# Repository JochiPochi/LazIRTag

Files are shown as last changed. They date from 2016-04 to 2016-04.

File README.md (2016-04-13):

# LaZIR Tag
Arduino based LaserTag System

BOM: https://docs.google.com/a/cyphyworks.com/spreadsheets/d/1MXdYDq4qyfqy3L1gnKtGEeZ4zqiRnnMYT2sN9ClZJ-U/edit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

REFERENCE:

IR Receiver Info - http://uk.farnell.com/vishay/tsop4838/ir-receiver-38khz/dp/4913190

IR Receiver Datasheet - http://www.farnell.com/datasheets/1693301.pdf

IR Reference - https://learn.adafruit.com/downloads/pdf/ir-sensor.pdf

Wifi Reference - https://espressif.com/en/products/esp8266/

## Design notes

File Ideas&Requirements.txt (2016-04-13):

Arena
  Two team bases
    Health Station
    Mounted Gun to protect base
      Kasey's Desk
      Skynet
  Cool Ambiance B)
  
Apparel
  Vest with Sensors
  
Weapons
  Weapon Types
    Semi-automatic Rifle - More points, less damage
      Trigger
    Shotgun - More damage, less points
      Trigger and Pump
  Speaker
    Shooting Sound Affect
    Universal Alerts
  Health Indication
    Can heal back at base
    Lose points for dying - have to "respawn" at health station
  Light indicator when shooting

Future Expansions
  CTF - electronic flag system
  Weaponized Grenade

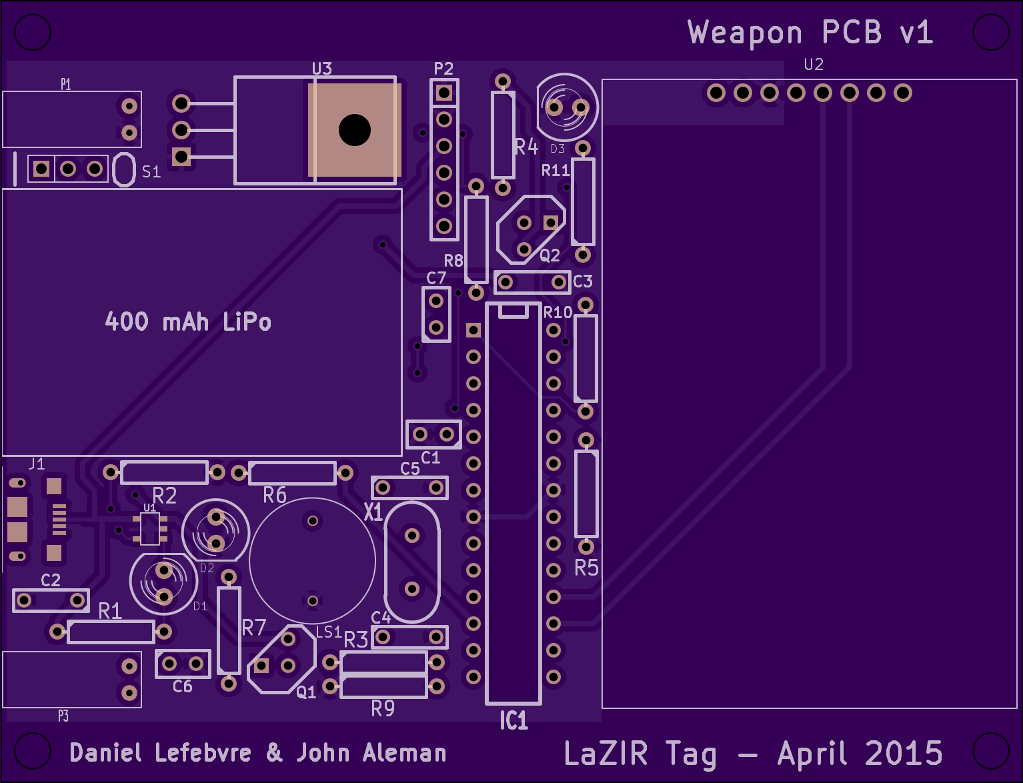
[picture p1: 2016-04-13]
KiCad/Rev1/Weapon/weap.png

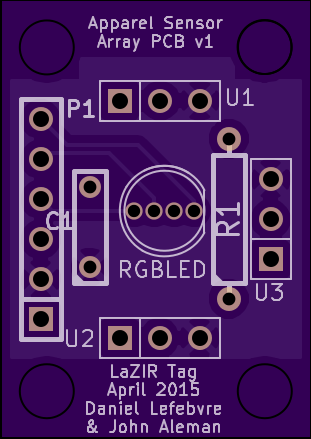
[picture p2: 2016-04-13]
KiCad/Rev1/IR-Reciever/irsens.png

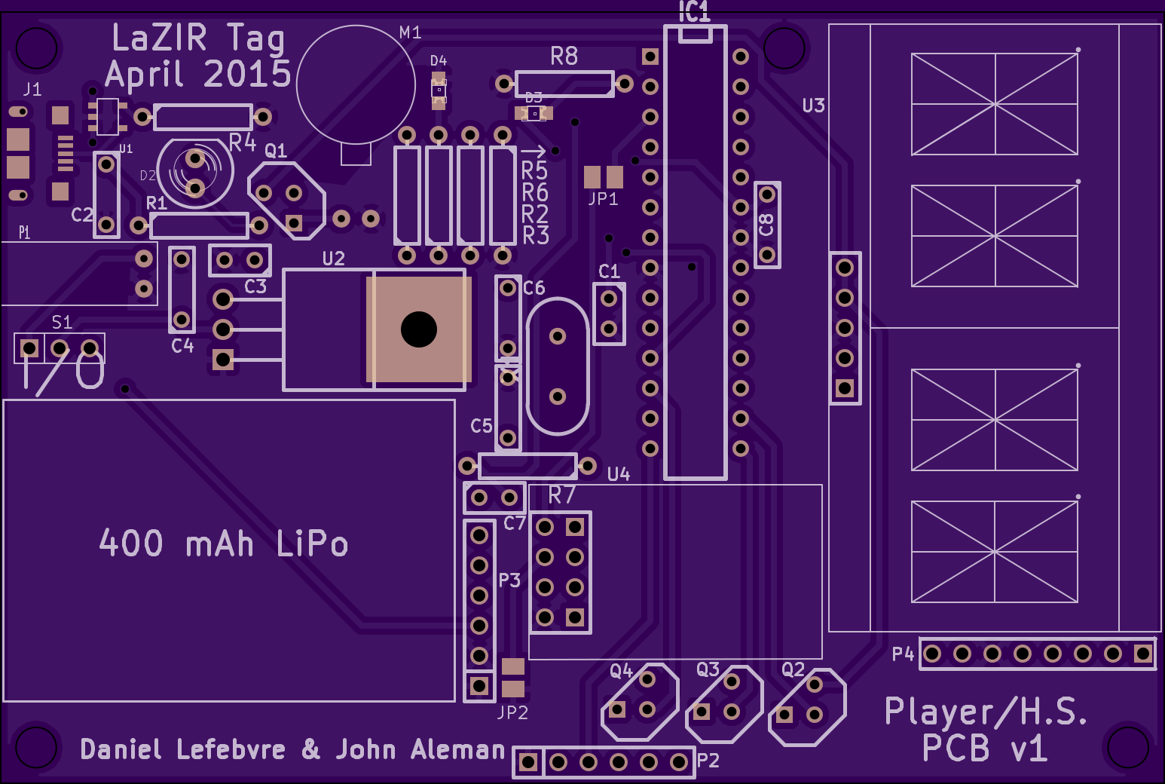
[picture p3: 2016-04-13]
KiCad/Rev1/Player-Health/plyrhs.png

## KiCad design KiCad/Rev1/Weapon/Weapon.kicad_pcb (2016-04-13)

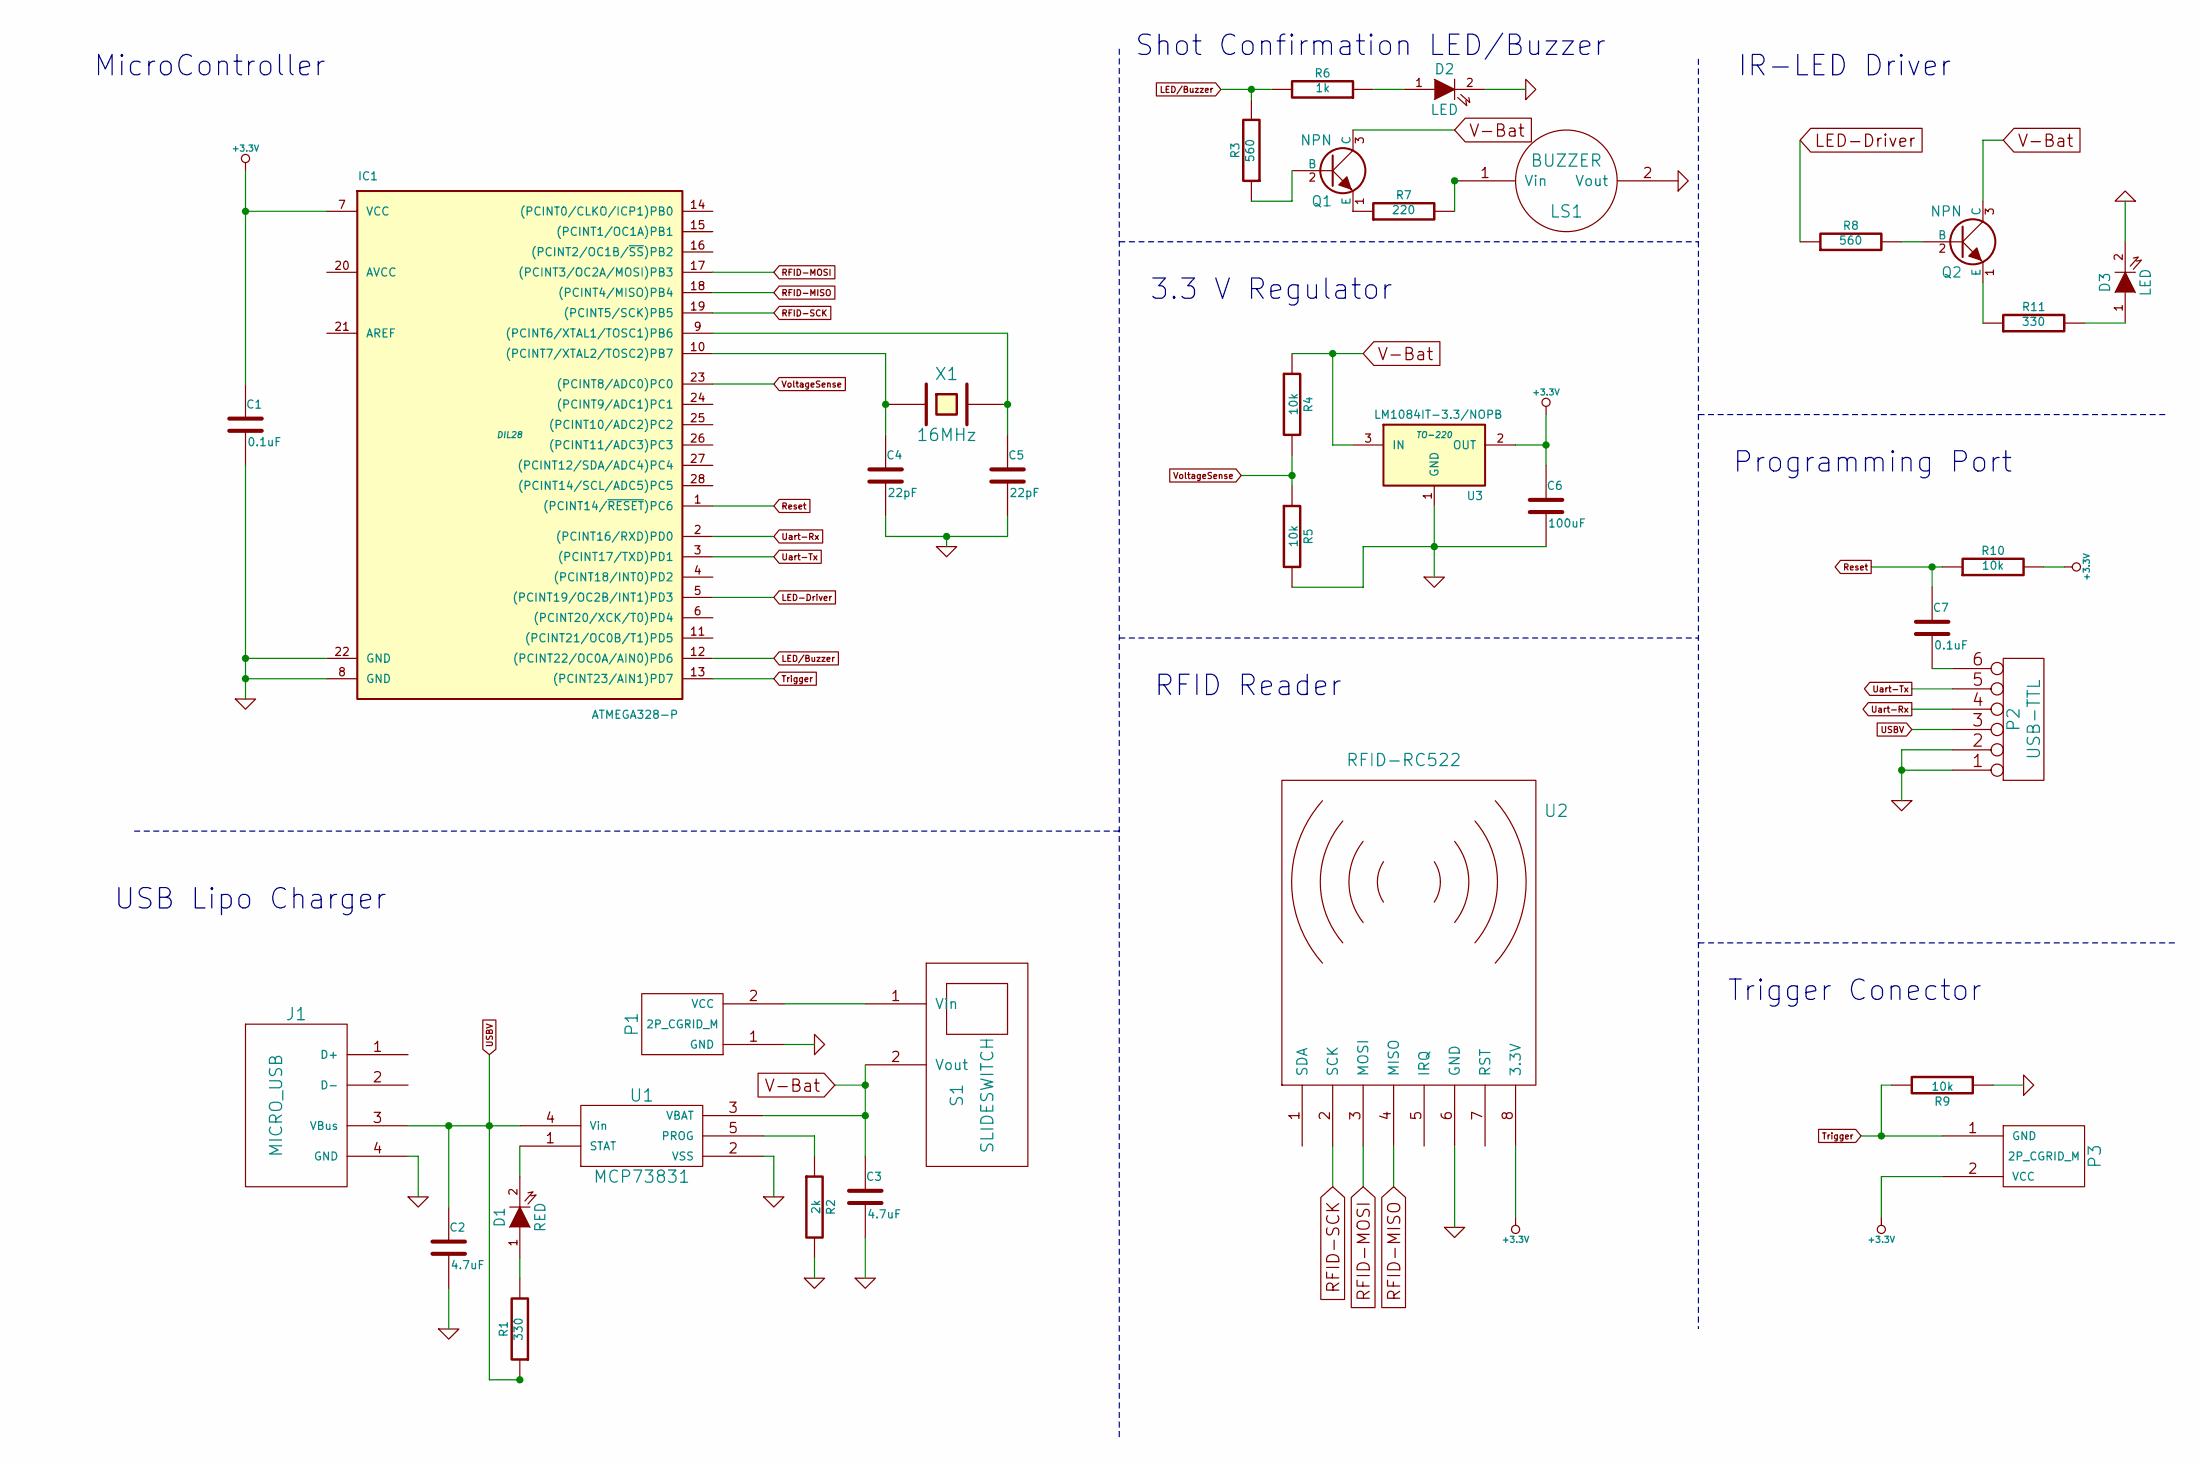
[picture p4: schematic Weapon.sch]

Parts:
C1, C7: 0.1uF
C2, C3: 4.7uF
C4, C5: 22pF
C6: 100uF
D1: RED
D2, D3: LED
IC1: ATMEGA328-P; DIL28
J1: MICRO_USB
LS1: BUZZER
P1: 2P_CGRID_M
P2: USB-TTL
P3: 2P_CGRID_M
Q1, Q2: NPN
R1, R11: 330
R2: 2k
R3, R8: 560
R4, R5, R9, R10: 10k
R6: 1k
R7: 220
S1: SLIDESWITCH
U1: MCP73831
U2: RFID-RC522
U3: LM1084IT-3.3/NOPB; TO-220
X1: 16MHz

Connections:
+3.3V: C1.1, C6.1, IC1.7 (VCC), P3.2 (VCC), R10.2, U2.8 (3.3V), U3.2 (OUT)
GND: C1.2, C2.2, C3.2, C4.2, C5.2, C6.2, D2.2 (K), D3.2 (K), IC1.8 (GND), IC1.22 (GND), J1.4 (GND), LS1.2 (Vout), P1.1 (GND), P2.1, P2.2, R2.2, R5.2, R9.1, U1.2 (VSS), U2.6 (GND), U3.1 (GND)
LED-Driver: IC1.5 ((PCINT19/OC2B/INT1)PD3), R8.1
LED/Buzzer: IC1.12 ((PCINT22/OC0A/AIN0)PD6), R3.2, R6.2
unnamed: P1.2 (VCC), S1.1 (Vin)
unnamed: D1.2 (K), U1.1 (STAT)
unnamed: D1.1 (A), R1.2
unnamed: R2.1, U1.5 (PROG)
unnamed: Q1.2 (B), R3.1
unnamed: Q1.1 (E), R7.1
unnamed: LS1.1 (Vin), R7.2
unnamed: D2.1 (A), R6.1
unnamed: C5.1, IC1.9 ((PCINT6/XTAL1/TOSC1)PB6), X1.2
unnamed: C4.1, IC1.10 ((PCINT7/XTAL2/TOSC2)PB7), X1.1
unnamed: C7.2, P2.6
unnamed: Q2.2 (B), R8.2
unnamed: D3.1 (A), R11.2
unnamed: Q2.1 (E), R11.1
RFID-MISO: IC1.18 ((PCINT4/MISO)PB4), U2.4 (MISO)
RFID-MOSI: IC1.17 ((PCINT3/OC2A/MOSI)PB3), U2.3 (MOSI)
RFID-SCK: IC1.19 ((PCINT5/SCK)PB5), U2.2 (SCK)
Reset: C7.1, IC1.1 ((PCINT14/~RESET~)PC6), R10.1
Trigger: IC1.13 ((PCINT23/AIN1)PD7), P3.1 (GND), R9.2
USBV: C2.1, J1.3 (VBus), P2.3, R1.1, U1.4 (Vin)
Uart-Rx: IC1.2 ((PCINT16/RXD)PD0), P2.4
Uart-Tx: IC1.3 ((PCINT17/TXD)PD1), P2.5
V-Bat: C3.1, Q1.3 (C), Q2.3 (C), R4.1, S1.2 (Vout), U1.3 (VBAT), U3.3 (IN)
VoltageSense: IC1.23 ((PCINT8/ADC0)PC0), R4.2, R5.1

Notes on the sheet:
MicroController
Shot Confirmation LED/Buzzer
3.3 V Regulator
RFID Reader
USB Lipo Charger
IR-LED Driver
Programming Port
Trigger Conector

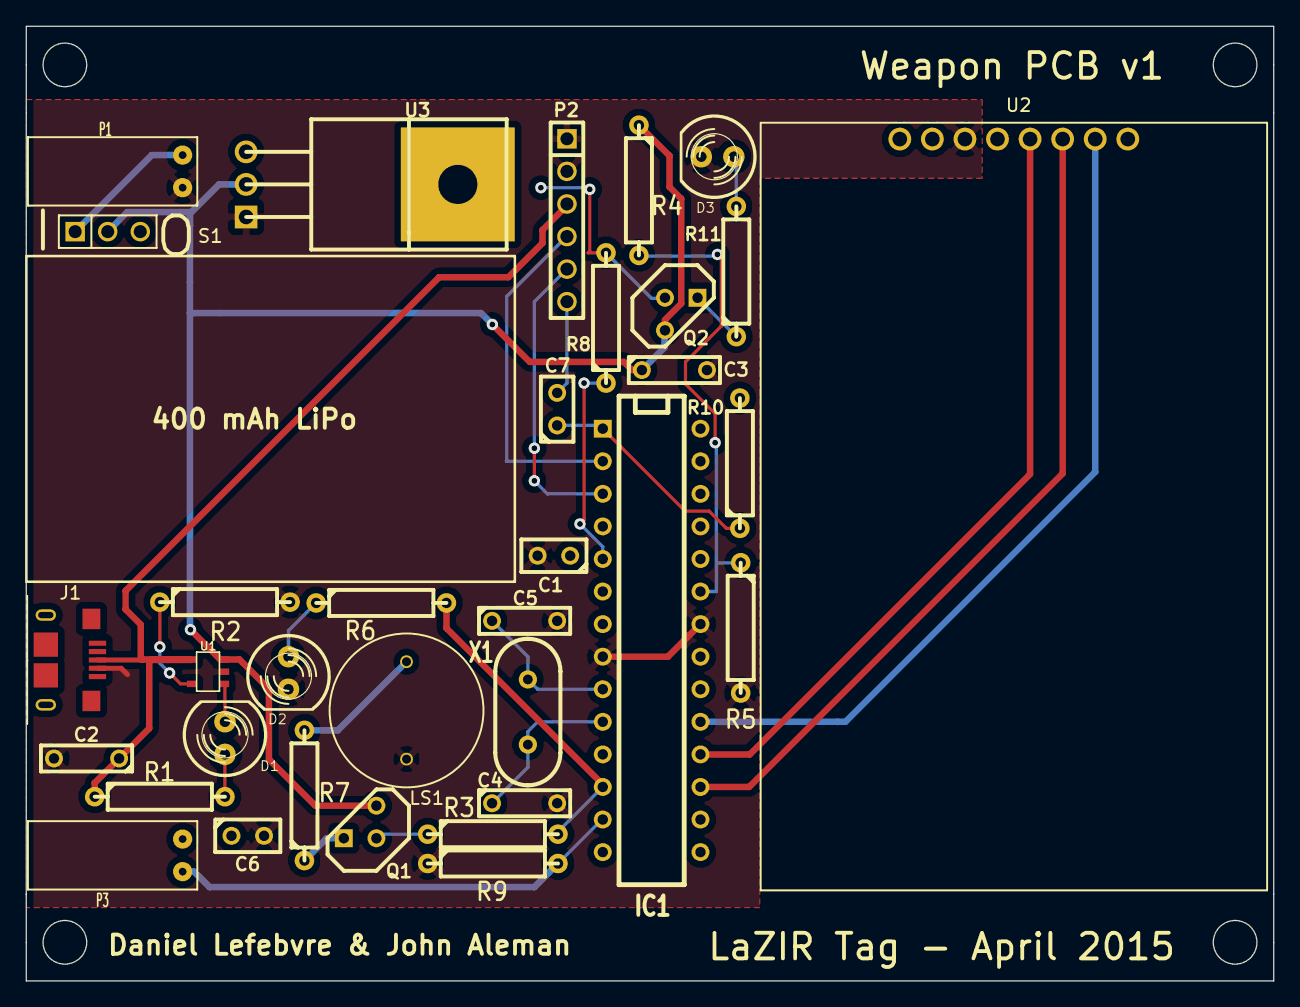
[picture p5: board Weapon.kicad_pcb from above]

Board: 2 copper layers, 97.3 x 74.4 mm, 34 parts (0 on the bottom side), 28 nets.

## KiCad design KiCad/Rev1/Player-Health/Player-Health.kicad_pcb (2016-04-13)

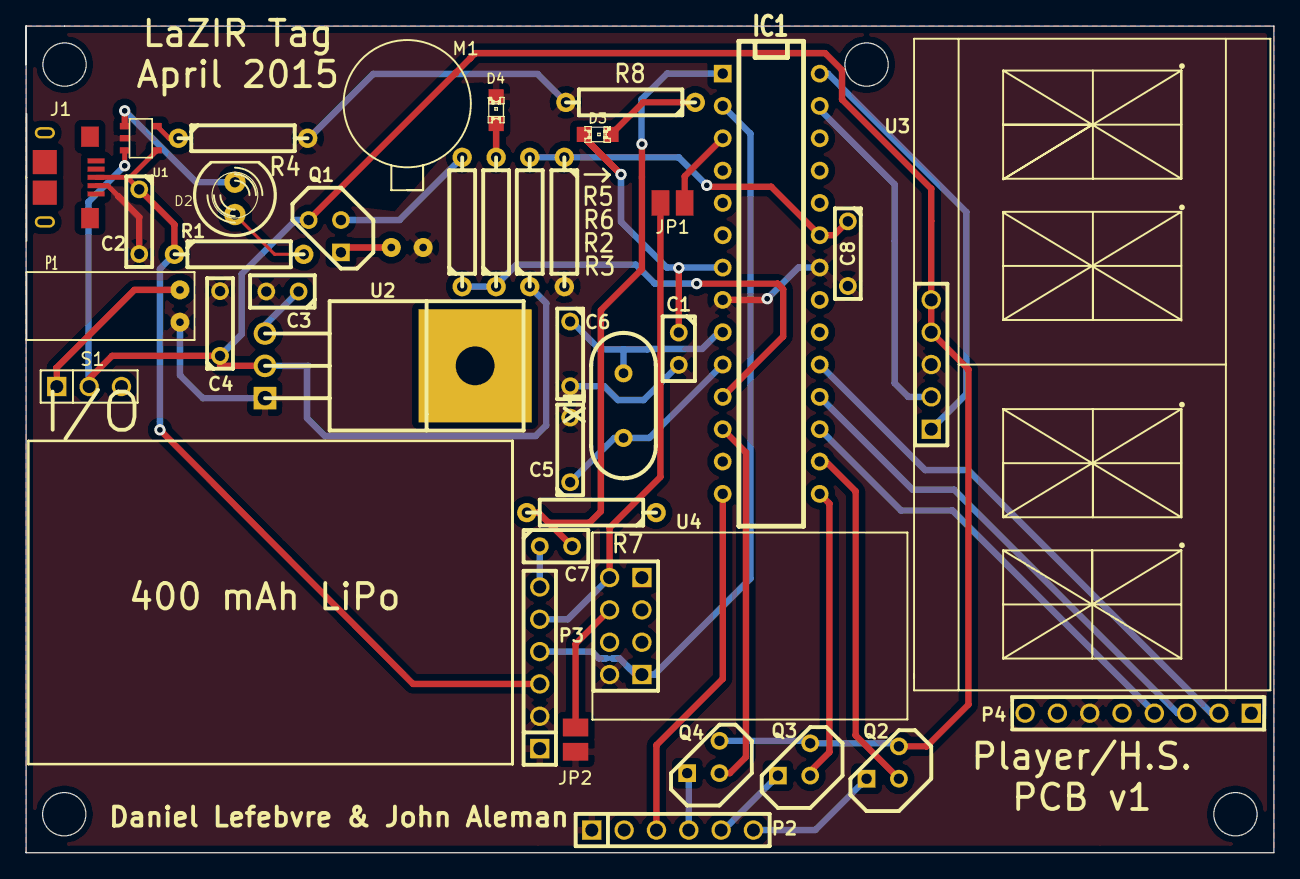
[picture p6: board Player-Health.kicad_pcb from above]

Board: 2 copper layers, 98.0 x 64.9 mm, 38 parts (0 on the bottom side), 34 nets.

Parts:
C1, C7: 0.1uF; C1
C2, C4: 4.7uF; C2
C3: 100uF; C1
C5, C6: 22pF; C2
C8: 4.7 uF; C2
D2: RED; LED-5MM
D3, D4: LED; LED-0805
IC1: ATMEGA328-P; DIP-28__300
J1: MICRO_USB; MicroUSB
JP1, JP2: JUMPER; JumperPads
M1: RUMBLE; RumbleMotor
P1: 2P_CGRID_M; 2PinMaleCGrid90Deg
P2: 6pM CGrid; PIN_ARRAY-6X1
P3: 6pM Header; PIN_ARRAY-6X1
P4: 8pF Header; pin_array_8x1
Q1, Q2, Q3, Q4: NPN; TO92
R1: 330; R4
R2, R3, R7: 10k; R4
R4: 2k; R4
R5: 560; R4
R6: 1k; R4
R8: 220; R4
S1: SLIDESWITCH; PIN_ARRAY_3X1
U1: MCP73831; SOT23-5
U2: LM1084IT-3.3/NOPB; TO220
U3: 14SLED; 14sLEDBP
U4: ESP8266; esploraWiFi
X1: CRYSTAL; HC-49V

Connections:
+3.3V: C1.1, C3.1, D3.1, IC1.7, P2.2, P4.8, R7.1, U2.2, U4.3, U4.7
GND: C1.2, C2.2, C3.2, C4.2, C5.2, C6.2, C8.2, D4.2, IC1.8, IC1.22, J1.4, JP2.2, M1.2, P1.1, P2.1, P3.1, P3.2, P4.6, R3.2, R4.2, R8.2, U1.2, U2.1, U3.3, U4.2
I2C CLK: IC1.28, U3.1
I2C DAT: IC1.27, U3.2
IR Sense: IC1.14, P2.3
LED B: IC1.15, Q3.2
LED G: IC1.12, Q4.2
LED R: IC1.16, Q2.2
MISO: IC1.18, P4.3
MOSI: IC1.17, P4.4
unnamed: P1.2, S1.1
unnamed: R4.1, U1.5
unnamed: D2.1, R1.2
unnamed: C7.1, P3.6
unnamed: M1.1, Q1.1
unnamed: JP2.1, U4.6
unnamed: D4.1, R6.2
unnamed: Q1.2, R5.2
unnamed: D3.2, R8.1
unnamed: IC1.3, JP1.1
unnamed: P2.4, Q4.1
unnamed: P2.5, Q3.1
unnamed: P2.6, Q2.1
unnamed: C5.1, IC1.10, X1.1
unnamed: C6.1, IC1.9, X1.2
unnamed: D2.2, U1.1
Reset: C7.2, IC1.1, R7.2
Rumble: IC1.11, R5.1, R6.1
SCK: IC1.19, P4.2
UART RX: IC1.2, P3.4, U4.1
UART TX: JP1.2, P3.5, U4.8
USBV: C2.1, J1.3, P3.3, R1.1, U1.4
VBatt: C4.1, Q1.3, Q2.3, Q3.3, Q4.3, R2.1, S1.2, U1.3, U2.3, U3.4, U3.5
VSense: C8.1, IC1.23, R2.2, R3.1

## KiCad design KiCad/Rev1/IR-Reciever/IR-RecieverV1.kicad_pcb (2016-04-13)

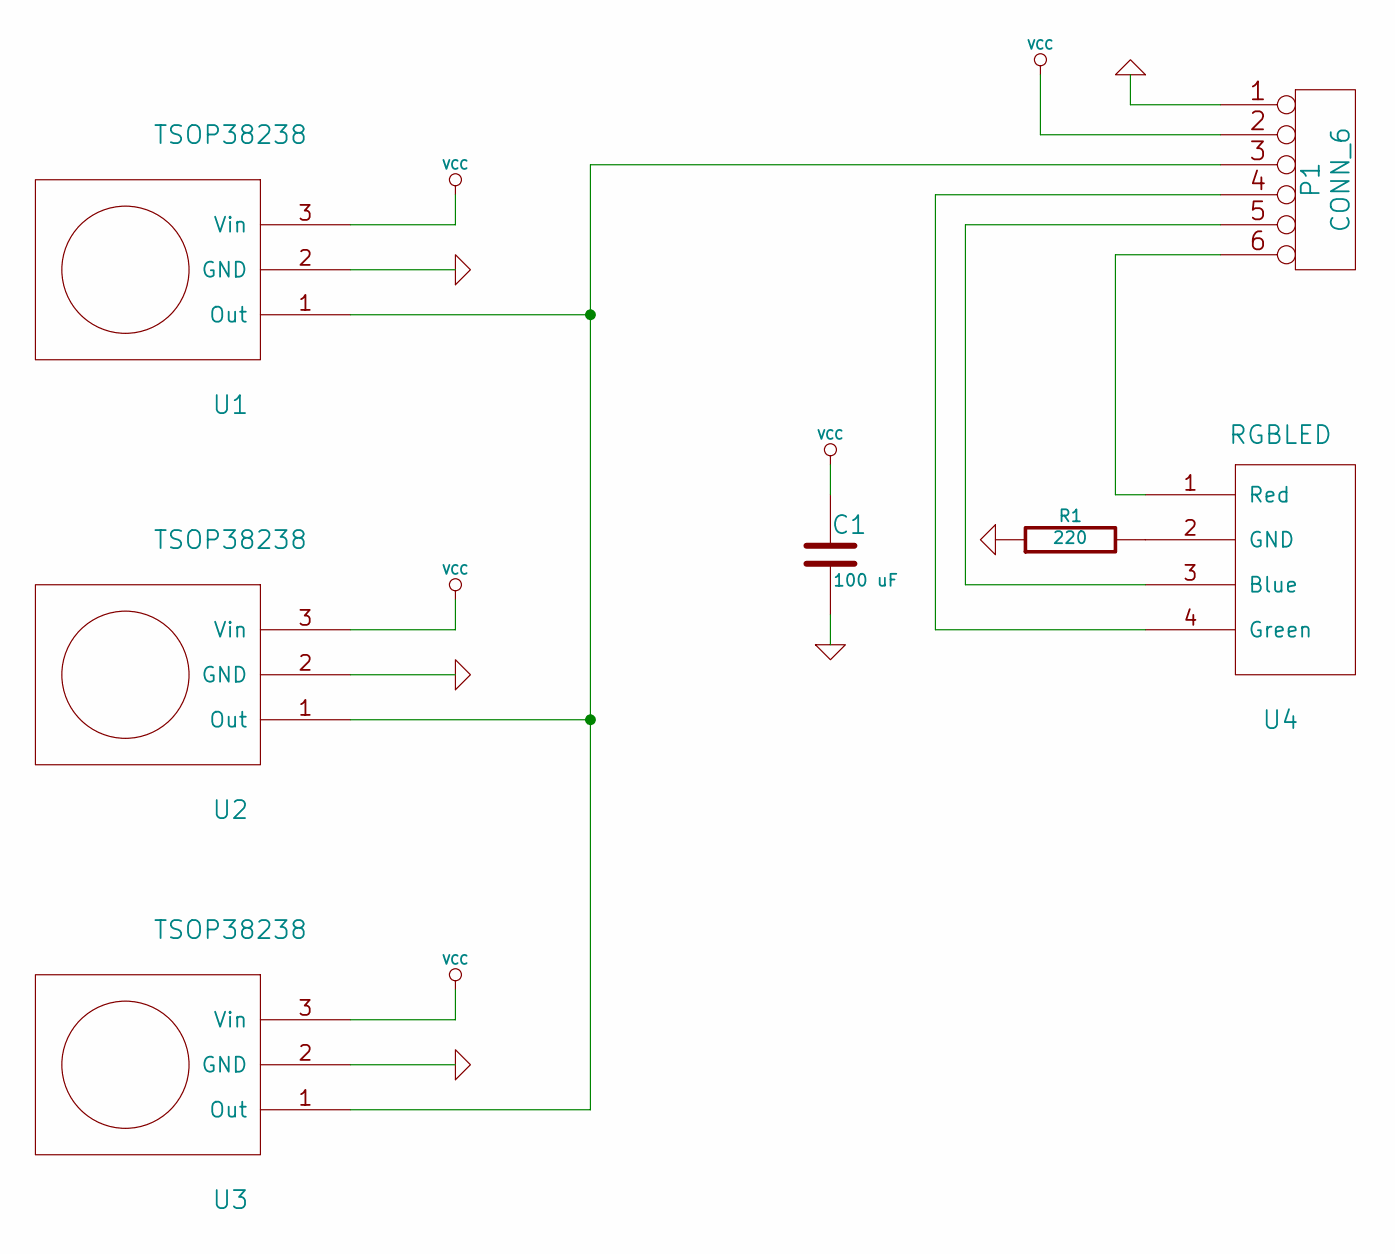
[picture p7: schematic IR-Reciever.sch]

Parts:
C1: 100 uF
P1: CONN_6
R1: 220
U1, U2, U3: TSOP38238
U4: RGBLED

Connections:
GND: C1.2, P1.1, R1.1, U1.2 (GND), U2.2 (GND), U3.2 (GND)
unnamed: P1.3, U1.1 (Out), U2.1 (Out), U3.1 (Out)
unnamed: P1.4, U4.4 (Green)
unnamed: P1.5, U4.3 (Blue)
unnamed: R1.2, U4.2 (GND)
unnamed: P1.6, U4.1 (Red)
VCC: C1.1, P1.2, U1.3 (Vin), U2.3 (Vin), U3.3 (Vin)

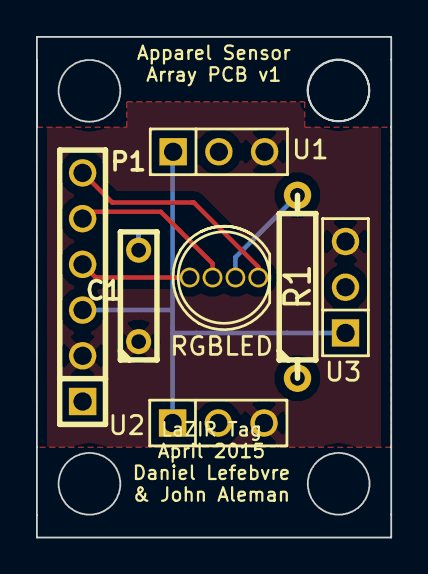
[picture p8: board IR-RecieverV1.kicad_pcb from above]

Board: 2 copper layers, 19.7 x 27.8 mm, 7 parts (0 on the bottom side), 7 nets.

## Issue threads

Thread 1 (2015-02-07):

Play/Pause with delayed repetition Sends two commands

dan52595, 2015-02-07:
Using the same delay that I read from the remote, I have an issue where the packet is received and acted upon twice if it's repeated, like it is from the remote. The code currently only loops through the packet once to prevent this.

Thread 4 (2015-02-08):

Get UART Zigbee network going (or Wifi)

JochiPochi, 2015-02-08:
Central system and wireless communication, updates everyone on what is doing on and when provides feedback when you shoot someone.
It would be ideal to get a Wifi network instead, but we would have to make sure that the range is possible. You can get 200 meters with Xbee in low power and 8 Km in the 900Mhz pro series. Wifi would be better but might be skimpy range wise.

JochiPochi, 2015-02-12:
So, it's final, we will be using WiFI modules, based on price and ease of use I guess

JochiPochi, 2015-02-12:
http://www.ebay.com/itm/ESP8266-Serial-WIFI-Wireless-Transceiver-Module-Send-Receive-LWIP-AP-STA-KN-/321660695250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

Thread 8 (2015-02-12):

BOM Discussions

JochiPochi, 2015-02-12:

JochiPochi, 2015-02-12:
So I found the LED Matrix driver for the player display :
http://tronixlabs.com/components/ics/led-driver/holtek-ht16k33-16-x-8-led-control-driver-ic/

It really might be cheaper to do it ourselves

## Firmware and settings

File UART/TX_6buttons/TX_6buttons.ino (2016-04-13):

// Initialize Switch States
int sS1 = 0; 
int pSS1 = 0;
int sS2 = 0; 
int pSS2 = 0;
int sS3 = 0; 
int pSS3 = 0;
int sS4 = 0; 
int pSS4 = 0;
int sS5 = 0; 
int pSS5 = 0;
int sS6 = 0; 
int pSS6 = 0;

uint8_t debounce = 500;

// Define Button Pins
#define switchOut1 13
#define switchIn1 12
#define switchOut2 11
#define switchIn2 10
#define switchOut3 9
#define switchIn3 8
#define switchOut4 7
#define switchIn4 6
#define switchOut5 5
#define switchIn5 4
#define switchOut6 3
#define switchIn6 2

// Initialize Packet Bytes
char syncByte = 0x6E; // Same with each message
char msgType; // Changes depending on message
char senderID;
char destID;
char remHealth;
char damMult;
char weapID;
char playerID;
char battCond;
char blank = 0x00; // Will be used twice to add room for expansion
char checksum;

void setup(){
  Serial.begin(9600); // Initialize Serial Comms
  pinMode(switchOut1, OUTPUT); 
  pinMode(switchIn1, INPUT); 
  digitalWrite(switchOut1, HIGH);
  pinMode(switchOut2, OUTPUT); 
  pinMode(switchIn2, INPUT); 
  digitalWrite(switchOut2, HIGH);
  pinMode(switchOut3, OUTPUT); 
  pinMode(switchIn3, INPUT); 
  digitalWrite(switchOut3, HIGH);
  pinMode(switchOut4, OUTPUT); 
  pinMode(switchIn4, INPUT); 
  digitalWrite(switchOut4, HIGH);
  pinMode(switchOut5, OUTPUT); 
  pinMode(switchIn5, INPUT); 
  digitalWrite(switchOut5, HIGH);
  pinMode(switchOut6, OUTPUT); 
  pinMode(switchIn6, INPUT); 
  digitalWrite(switchOut6, HIGH);
}

void loop(){
  sS1 = digitalRead(switchIn1); 
  sS2 = digitalRead(switchIn2); 
  sS3 = digitalRead(switchIn3); 
  sS4 = digitalRead(switchIn4);
  sS5 = digitalRead(switchIn5); 
  sS6 = digitalRead(switchIn6);
  if (sS1  == 1 || sS2 == 1 || sS3 == 1 || sS4 == 1 || sS5 == 1 || sS6 == 1){
    if (sS1 != pSS1 && sS1 == 1){ // If it's button 1
      msgType = 0x0B;
      senderID = 0xA0; // Send customized info for this example packet
      destID = 0x00;
      weapID = 0x00; // From Team A's health station, no weapon
      playerID = 0xA9;
      battCond = 0xFC;
    }
    if (sS2 != pSS2 && sS2 == 1){ // or button 2
      msgType = 0x0B;
      senderID = 0xB0; // Change the bytes to test comms
      destID = 0x00;
      weapID = 0x00; // From Team B's health station
      playerID = 0xBD;
      battCond = 0xFE;
    }
    if (sS3 != pSS3 && sS3 == 1){ // or even button 3
      msgType = 0x0B;
      senderID = 0xA9;
      destID = 0x00;
      weapID = 0xAD; // Player got shot with this gun
      playerID = 0xBD;
      battCond = 0xFF;
    }
    if(sS4 != pSS4 && sS4 == 1){
      msgType = 0x0A;
      senderID = 0x00;
      destID = 0xA0;
      remHealth = 0xDA;
      damMult = 0x01;
    }
    if(sS5 != pSS5 && sS5 == 1){
      msgType = 0x0A;
      senderID = 0x00;
      destID = 0xB0;
      remHealth = 0xC2;
      damMult = 0x01;
    }
    if(sS6 != pSS6 && sS6 == 1){
      msgType = 0x0A;
      senderID = 0x00;
      destID = 0xA9;
      remHealth = 0x3D;
      damMult = 0x02;
    }

    //    for (int i = 1; i == 20; i++){
    if (msgType == 0x0A){
      checksum = (0xFF - (syncByte+msgType+senderID+destID+remHealth+damMult));
//      Serial.write(syncByte); 
//      Serial.write(msgType); 
//      Serial.write(senderID); 
//      Serial.write(destID);
//      Serial.write(remHealth);
//      Serial.write(damMult);
//      Serial.write(blank);
//      Serial.write(blank);
//      Serial.write(checksum);
      Serial.println(syncByte, HEX);
      Serial.println(msgType, HEX);
      Serial.println(senderID, HEX);
      Serial.println(destID, HEX);
      Serial.println(remHealth, HEX);
      Serial.println(damMult, HEX);
      Serial.println(blank, HEX);
      Serial.println(blank, HEX);
      Serial.println(checksum, HEX);
      //        delay(1);
      //      }
    }
    //    for (int i = 1; i == 20; i++){
    if (msgType == 0x0B){
      checksum = (0xFF - (syncByte+msgType+senderID+destID+weapID+playerID+battCond));
      Serial.write(syncByte); // Send packet with customized info based on button
      Serial.write(msgType);
      Serial.write(senderID);
      Serial.write(destID);
      Serial.write(weapID);
      Serial.write(playerID);
      Serial.write(battCond);
      Serial.write(blank);
      Serial.write(blank);
      Serial.write(checksum);
      //        delay(1);
      //      }
    }
  }
  // Update Switch State Variables
  pSS1 = sS1; 
  pSS2 = sS2; 
  pSS3 = sS3; 
  pSS4 = sS4; 
  pSS5 = sS5; 
  pSS6 = sS6;
}

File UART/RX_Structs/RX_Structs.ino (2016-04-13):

#include "packA_B.h"

int incByte = 0;	// for incoming serial data
int incLen = 0; // Initialize an incoming packet length
int packetLen = 0;
char cs = 0;

char mestyp = 0;

packA incomingA;
packB incomingB;

void setup() {
  Serial.begin(9600);	// opens serial port, sets data rate to 9600 bps
  Serial1.begin(9600);
  while (!Serial) ;

  incomingA.syncByte = 0x6E;
  incomingA.senderID = 0x00;
  incomingA.blank1 = 0x00;
  incomingA.blank2 = 0x00;

  incomingB.syncByte = 0x6E;
  incomingB.destID = 0x00;
  incomingB.blank1 = 0x00;
  incomingB.blank2 = 0x00;
}

void loop() {

  // send data only when you receive data:
  if (Serial1.available() > 0) {
    // read the incoming byte:
    incByte = Serial1.read();
    if (mestyp == 0){
      if (incByte == 0x0A){
        incLen = 9;
        incomingA.msgType = 0x0A;
        mestyp = 0x0A;
      }
      else if(incByte == 0x0B){
        incLen = 10;
        incomingB.msgType = 0x0B;
        mestyp = 0x0B;
      }
    }

    if (mestyp == 0x0A){
      if (packetLen == 3){
        incomingA.destID = incByte;
      }
      if (packetLen == 4){
        incomingA.remHealth = incByte;
      }
      if (packetLen == 5){
        incomingA.damMult = incByte;
      }
      if (packetLen == 8){
        incomingA.checksum = incByte;
      }
    }
    if (mestyp == 0x0B){
      if (packetLen == 2){
        incomingB.senderID = incByte;
      }
      if (packetLen == 4){
        incomingB.weapID = incByte;
      }
      if (packetLen == 5){
        incomingB.playerID = incByte;
      }
      if (packetLen == 6){
        incomingB.battCond = incByte;
      }
    }
    packetLen++;


  }
  if (packetLen == incLen){
    if (mestyp == 0x0A){
      Serial.print("Sync Byte:"); 
      Serial.print(" "); 
      Serial.println(incomingA.syncByte, HEX);
      Serial.print("Message Type:"); 
      Serial.print(" "); 
      Serial.println(incomingA.msgType, HEX);
      Serial.print("Sender ID:"); 
      Serial.print(" "); 
      Serial.println(incomingA.senderID, HEX);
      Serial.print("Destination ID:"); 
      Serial.print(" "); 
      Serial.println(incomingA.destID, HEX);
      Serial.print("Remaining Health:"); 
      Serial.print(" "); 
      Serial.println(incomingA.remHealth, HEX);
      Serial.print("Damage Multiplier:"); 
      Serial.print(" "); 
      Serial.println(incomingA.damMult, HEX);
      Serial.print("Blank:"); 
      Serial.print(" "); 
      Serial.println(incomingA.blank1, HEX);
      Serial.print("Blank:"); 
      Serial.print(" "); 
      Serial.println(incomingA.blank2, HEX);
      Serial.print("Checksum:"); 
      Serial.print(" "); 
      Serial.println(incomingA.checksum, HEX);
    }
    if (mestyp == 0x0B){
      Serial.print("Sync Byte:"); 
      Serial.print(" "); 
      Serial.println(incomingB.syncByte, HEX);
      Serial.print("Message Type:"); 
      Serial.print(" "); 
      Serial.println(incomingB.msgType, HEX);
      Serial.print("Sender ID:"); 
      Serial.print(" "); 
      Serial.println(incomingB.senderID, HEX);
      Serial.print("Destination ID:"); 
      Serial.print(" "); 
      Serial.println(incomingB.destID, HEX);
      Serial.print("Weapon ID:"); 
      Serial.print(" "); 
      Serial.println(incomingB.weapID, HEX);
      Serial.print("Player ID:"); 
      Serial.print(" "); 
      Serial.println(incomingB.playerID, HEX);
      Serial.print("Battery Condition:"); 
      Serial.print(" "); 
      Serial.println(incomingB.battCond, HEX);
      Serial.print("Blank:"); 
      Serial.print(" "); 
      Serial.println(incomingB.blank1, HEX);
      Serial.print("Blank:"); 
      Serial.print(" "); 
      Serial.println(incomingB.blank2, HEX);
      Serial.print("Checksum:"); 
      Serial.print(" "); 
      Serial.println(incomingB.checksum, HEX);
    }
    Serial.println("");
    packetLen = 0;
    mestyp = 0;
  }
}

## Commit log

2016-04-13 This is very broken code for the Gun FW I'll branch, fix and merge
    [Gun-FW.ino, IRremote5.cpp, IRremoteInt5.h]
2016-04-13 Kicad Init
    [IR-Reciever.kicad_pcb, IR-Reciever.sch]
2016-04-13 Adding most recent Serial test codes
    Combination of RX_structs and TX_6Buttons currently does not work.
    Debugging as you read
    [RX_Structs.ino, TX_6buttons.ino]
2016-04-13 Cleaning up a bit, still buggy
    [RX_Structs.ino, TX_6buttons.ino]
2016-04-13 Adding more KiCad material
    Second revision of apparel sensors and start of wrist display project
    [IR-RecieverV2.kicad_pcb]
2016-04-13 Started on the PCB design for the Weapon
    [Weapon.sch]
2016-04-13 Started Schematic for Wrist Display
    Includes MicroUSB charging shematic
    [Wrist Display Unit.sch]
2016-04-13 Added Wireless Device
    Component in Library
2016-04-13 Weapon Schematic Ready
    [Weapon.sch]
2016-04-13 Updated Components - 2:45 AM
    Nearly all of the weapon components delegated
    [Wrist Display Unit.sch]
2016-04-13 3/19 Progress
    KiCad - weapon component to module selection and pcb file created.
    All schematic components on net and allocated
    [Weapon.kicad_pcb, Weapon.sch]
2016-04-13 3/29 KiCad Updates
    Revised Weapon PCB, renamed wrist display unit and more
    [IR-RecieverV2.kicad_pcb, Player-Health.sch, Weapon.sch]
2016-04-13 Revert "3/29 KiCad Updates"
    This reverts commit a2529da1b40b1f6e0e832ed1976ed3be41434859.
    [IR-RecieverV2.kicad_pcb, Weapon.kicad_pcb, Weapon.sch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]
2016-04-13 Revert "Revert "3/29 KiCad Updates""
    This reverts commit 46467126b97e8d3ee2ff82587e11af580e6d6854.
    [IR-RecieverV2.kicad_pcb, Player-Health.sch, Weapon.sch]
2016-04-13 Through Holes & Player/Health Schematic
    I'm re-uploading the Apparel Sensor and Weapon PCBs with extended edges
    and through holes on the corners for mounting. This also includes the
    first draft of the Player/Health Schematic. Please critique
    [IR-RecieverV2.kicad_pcb, Player-Health.sch, Weapon.kicad_pcb]
2016-04-13 Quick Update #1 4/16
    [IR-RecieverV2.kicad_pcb, Player-Health.sch, Weapon.kicad_pcb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]
2016-04-13 Quick Update #2 4/16
    [Weapon.kicad_pcb]
2016-04-13 Quick Update #3 4/16
    [Weapon.kicad_pcb]
2016-04-13 Quick Update #4 4/16
    [Weapon.kicad_pcb]
2016-04-13 Quick Update #5 4/16
    [Weapon.kicad_pcb]
2016-04-13 Quick Update #6 4/16
    Hopefully the last changes to the ir receiver pcb and weapon pcb
    [IR-RecieverV2.kicad_pcb, Weapon.kicad_pcb]
2016-04-13 Quick Update #1 4/17
    Finished PCBs for Apparel Sensor and Weapon, ready for review
    Finished Schematic, Netlist, and Component Assignment for Player/Health
    Started PCB with components and text for Player/Health
    New Component footprints for 8x1 pin array, wifi module, and
    alphanumeric
    [Player-Health.kicad_pcb, Player-Health.sch]
2016-04-13 Quick Update #2 4/17
    Added Jumpers to Schematic, Net List and PCB, but failing connectivity
    [Player-Health.kicad_pcb, Player-Health.sch]
2016-04-13 Quick Update #3 4/17
    [Player-Health.kicad_pcb, Player-Health.sch]
2016-04-13 Last Update for the Night 4/17(4/16)
    General PCB layout, fix to jumper pads
    [Player-Health.kicad_pcb, Player-Health.sch]
2016-04-13 Update #1 4/17
    First Draft of Player/Health PCB for review.
    Added on/off indicators to weapon pcb for slideswitch
    [Player-Health.kicad_pcb, Weapon.kicad_pcb]
2016-04-13 Update #2 4/17
    Shrunk board to be >10cm
    [Player-Health.kicad_pcb]
2016-04-13 Quick Update #1 4/24
    [Player-Health.kicad_pcb, Player-Health.sch]
2016-04-13 Quick Update #2 4/24
    [Player-Health.kicad_pcb, Player-Health.sch]
2016-04-13 Quick Update #3 4/24
    Adjusted keepout areas
    [Player-Health.kicad_pcb]
2016-04-13 Quick Update #4 4/24
    [Player-Health.kicad_pcb]
2016-04-13 Quick Update #5 4/24
    [Player-Health.kicad_pcb]
2016-04-13 Quick Update #6 4/24
    [Player-Health.kicad_pcb]
2016-04-13 Quick Update #1 4/28
    Added resistor (220) to buzzer in weapon sch,net,pcb
    [Weapon.kicad_pcb, Weapon.sch]
2016-04-13 Quick Update #2 4/28
    Changes to Weapon PCB
    [IR-RecieverV2.kicad_pcb, Weapon.kicad_pcb]
2016-04-13 Quick Update #3 4/28
    Refinement of text placement
    [Weapon.kicad_pcb]
2016-04-13 Ordered Weapon Proto
    Tada... Holy Crap
    [IR-RecieverV2.kicad_pcb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]
2016-04-13 Final Push 4/28ish
    Updated Formatting of Player/Health PCB
    [Player-Health.kicad_pcb]
2016-04-13 Quick Update 5/1
    [Player-Health.sch]
2016-04-13 Quick Update #2 5/1
    Night night
    [IR-Reciever.sch, Player-Health.sch]
2016-04-13 Quick Update #3 5/1
    Potential last changes before ordering ir receiver and player boards
    [IR-RecieverV0.kicad_pcb, IR-RecieverV1.kicad_pcb, IR-RecieverV2.kicad_pcb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]
2016-04-13 Quick Update #4 5/1
    Added gerber files to order boards
    [IR-RecieverV1-B_Cu.gbl, IR-RecieverV1-B_Mask.gbs, IR-RecieverV1-B_SilkS.gbo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]
2016-04-13 Gerber Files
    Weird git stash business saved gerber files, I guess
    [IR-Reciever.sch, IR-RecieverV0.kicad_pcb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]
2016-04-13 Update Packets.txt
    A lot of structure here was made before we selected WiFi as the wireless interface. Simplified the protocol to reflect that.
